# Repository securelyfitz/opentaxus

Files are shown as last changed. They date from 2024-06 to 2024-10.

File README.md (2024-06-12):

# OpenTaxus 

| [Readme](README.md) | [Using the Badge](docs/BADGE.md) | [Playing the Game](docs/GAME.md) | [Software Development](docs/DEVELOP.md) | [Badge Hardware](docs/HARDWARE.md) |
| --- | --- | --- | --- | --- |

## Badge Game

The OpenTaxus Badge is designed for playing the Attribution Game.
Similar to the board game Clue or some versions of Carmen Sandiego,
you need to figure out who the threat actor, attack tool, and victim
are for each round of the game. You do this by trading cards (or
'clues') as well as your self-entered alibi name with others
at the conference.

## Attribution Game basics

In order to play in the Attribution Game, you will need to enter a name or handle when you first turn on your badge. This will stay through power cycles. It can be cleared in your settings which will force you to enter a new one.

To trade cards with someone, scroll left or right until you get to the "OpenTaxus" screen.
Once there, press the toggle up, and place your badge edge at the top of the screen against
the same badge edge of the person you are trading with. You should see once your card has
been transmitted and you have received a card from them.

You can check your collected cards by scrolling right from the "OpenTaxus" screen.

When you collect enough cards, the one remaining is the solution that completes the phrase. There are 6 games to play through - try them all!

Please see [Playing the Game](docs/GAME.md) for more details

## Repo Contents

This repository contains the hardware and software for
the badge and game. We hope it is useful for those who wish to hack
the badges and game, anyone who wants to use the badge to learn some
circuitpython, as well as others who might like to reuse some or all
of it for other projects.

The badge hardware was designed and produced by @securityfitz, with variants being used for BSidesSF 2024 and Labscon.
The badge software is a fork of the Labscon badge software, further mangled by @rlc4, @lanrat, and @securelyfitz.

## Event Badge Designer Instructions

OpenTaxus is intended to be be a drop-in electronic badge that works from the start. While you can use the badge as it's presented here if you plan to use it for an event or organization, you may want to customize the appearance of the badge, and possibly some of the text and programming. 

### Suggested customizations:
	
#### Physical Appearance:
* Add custom artwork such as your logo to the badges KiCad files (found in the [hardware](/hardware) folder). 
*  Add in the name of the artist and contributors to the silkscreen.
* Include the repo for your code or events in the silkscreen on the back of the badge.

#### Electronic text:
* There are a number of custom strings that can be adjusted within the [genfiles.py](./configs/genfiles.py) file. In particular, you may want to change line 121 to say the name of your event or organization instead of "A mysterious group".
* The same file also includes other bits of flavor text that could be customized to match your event's theme or location.
* Changing the menu text of the badge to show your event name instead of "OpenTaxus" can be done on lines 23 and 139 of [home.py](./software/home.py)
* Sponsor names can be added within [home.py](./software/home.py) around line 144.

#### Misc:
* You may also want to change the file that you're reading now ([README.md](README.md)) to welcome your attendee's, ctf players, etc.

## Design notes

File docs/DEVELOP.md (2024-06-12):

# Develop with the OpenTaxus Badge

| [Readme](../README.md) | [Using the Badge](BADGE.md) | [Playing the Game](GAME.md) | [Software Development](DEVELOP.md) | [Badge Hardware](HARDWARE.md) |
| --- | --- | --- | --- | --- |

## Developing for the badge

Version: CircuitPython 9.0.4; Seeeduino XIAO RP2040

Make sure you use version compatible libraries

### Installing CircuitPython

When the RP2040 boots, it checks for valid data in the spi flash. If it doesn't,
it boots into USB boot-loader mode and shows up as a drive labeled RPI-RP2.
[Download and copy the .UF2 file](https://circuitpython.org/board/seeeduino_xiao_rp2040/)
to the drive and it will reboot into CircuitPython.
If you need to reinstall for any reason, short the 'BOOT' test pads while resetting
the RP2040 and it will go back to the boot-loader mode.

### Installing The Attribution Game

Once CircuitPython is installed, when the badge is plugged in it will show
both a serial port and a drive labeled CIRCUITPY. Copy the entire contents
of `/software/` in this repository to that drive. the badge will reboot and run the code.

### Provisioning the game data

The `/config/` directory contains some text files with data specific to
the game. These will be copied along with the rest of the code:

- genfiles generates a pair of keys, and creates 50 variations of game*.csv files
- game*.csv has all the possible clues for each game, and is provisioned with one signed clue per game
- seed.txt needs to be filled with a seed for the random choice of solutions
- priv.json and pub.json are generated by genfiles and contain the game keys which can be used to authenticate the signed
  clues you receive. This is generated by the controller, the public key is copied to all badges

Details about the hardware can be found in [HARDWARE](docs/HARDWARE.md)

## Software

- `/software/` contains the code on the badge
- `/flash/` contains files and tools for automatically flashing badges
- `/config/` contains tools to generate all of the encrypted badge configurations

### Architecture

Most functions are wrapped inside classes with the priority to make the top level
code more clean and readable versus sticking to a clean object model.

All functions should be non-blocking and quick to make sure the UI doesn't get
frozen and button presses don't get missed. This means stuff like checking for
enough UART valid data before reading it, and scheduling timed actions based on
timestamps instead of sleep() calls

#### Dependencies

- core circuitpython libraries: time,board,busio,pulseio,digitalio,displayio,
  terminalio
- additional adafruit libraries in `/software/lib/`: debouncer,
  ticks, displayio_ssh1106, imageload, display_text

#### Support modules

-  Fake_IRDA.py wraps the UART interface, handles enabling/disabling the
   IRDA enable pin, and stuffing/unstuffing the bytes that are transmitted
   to work with the IRDA phy in the nonstandard way we use it
-  Five_Way_Dpad.py wraps the dpad with the Adafruit Debouncer including
   all setup and a few helper functions for checking all buttons at once. The
   non-blocking update() function needs to be run periodically to capture all
   button presses.
-  sh1106_ui.py/ssd1306.py wraps the I2C display interface, handles the overall display
   view, and creates a separate group for each of the navigation pages. The
   non-blocking show() function should be called periodically to make sure the
   correct view is displayed and to manage the transition animations
-  disp.py wraps the functionality of the pages. The class handles initialization,
   managing the display view, underlying data and operations. Most of this is
   handled in a non-blocking update() function that returns the next state

## Screen

* https://www.arduino.cc/reference/en/libraries/oled-ssd1306-sh1106/
* https://docs.circuitpython.org/projects/displayio_sh1106/en/latest/api.html

Driven by: https://docs.circuitpython.org/en/latest/shared-bindings/displayio/

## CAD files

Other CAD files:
flash/dock.scad

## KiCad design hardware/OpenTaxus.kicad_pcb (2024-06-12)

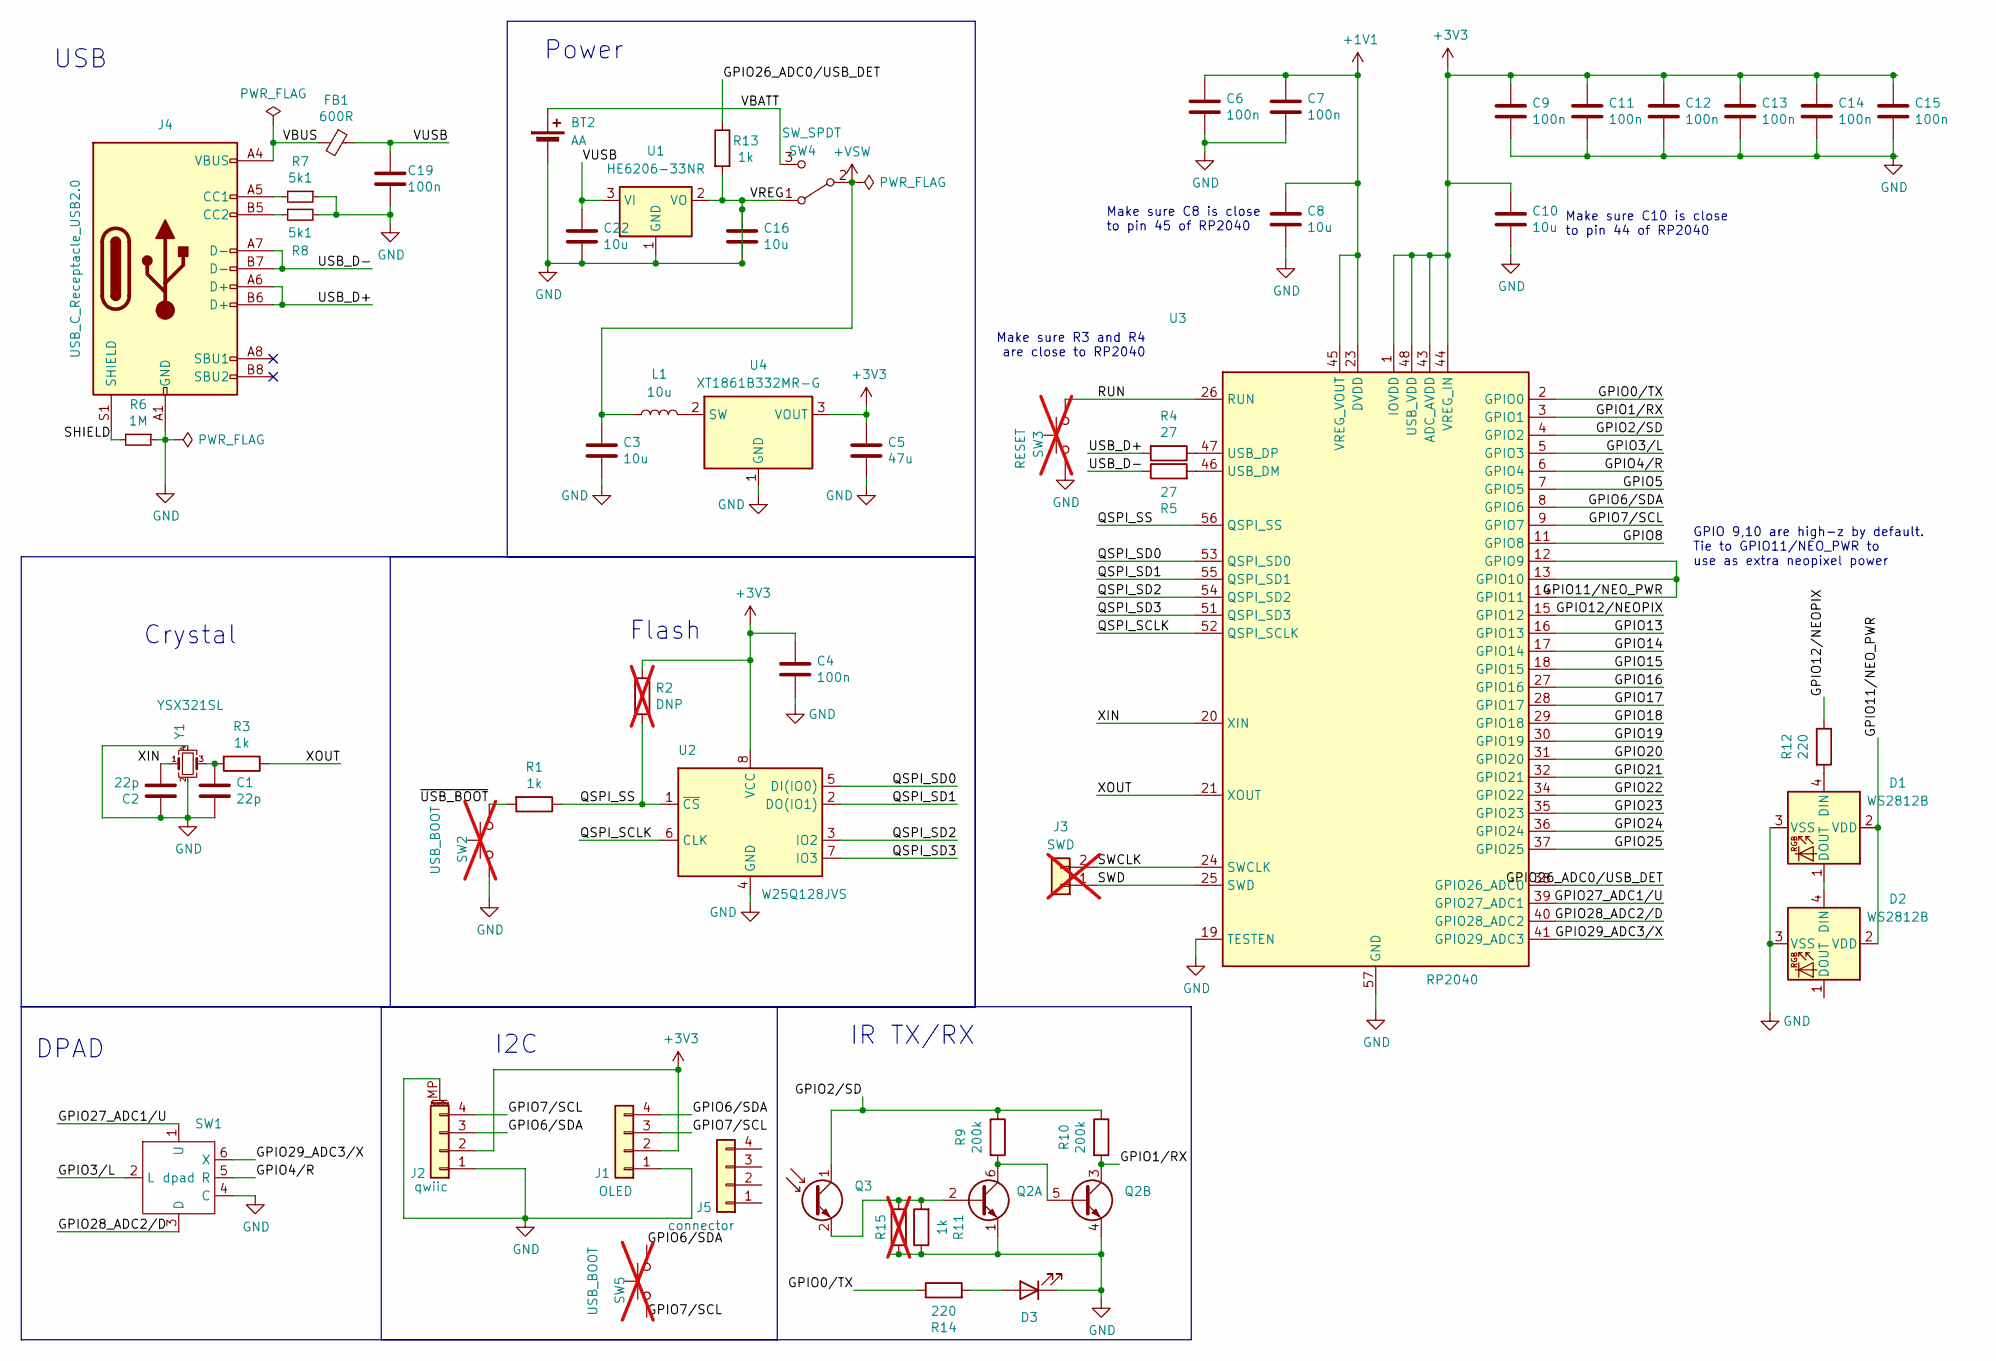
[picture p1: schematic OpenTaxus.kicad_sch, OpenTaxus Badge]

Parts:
BT2: AA; BatteryHolder_Keystone_2460_1xAA; LCSC C5290181
C1, C2: 22p; C_0402_1005Metric; LCSC C106203
C3, C8, C10, C16, C22: 10u; C_0402_1005Metric; LCSC C15525
C4, C6, C7, C9, C11, C12, C13, C14, C15, C19: 100n; C_0402_1005Metric; LCSC C100072
C5: 47u; C_0805_2012Metric; LCSC C16780
D1, D2: WS2812B; LED_WS2812B_PLCC4_1.0x1.0mm; LCSC C5349953
D3: IR12-21C/TR8; IR12-21C-TR8; LCSC C53672
FB1: 600R; L_0402_1005Metric; LCSC C76886
J1: OLED; PinHeader_1x04_P2.54mm_Vertical; LCSC C5248080
J2: qwiic; JST_SH_SM04B-SRSS-TB_1x04-1MP_P1.00mm_Horizontal; LCSC C7433425
J3: SWD; SolderJumper-2_P1.3mm_Open_RoundedPad1.0x1.5mm; LCSC DNP; not fitted
J4: USB_C_Receptacle_USB2.0; USB_C_Receptacle_HRO_TYPE-C-31-M-12; LCSC C2927038
J5: connector; PinHeader_1x04_P2.54mm_Vertical; LCSC C2902691
L1: 10u; L_1008_2520Metric; LCSC C602018
Q2: BC847BS; SOT-363_SC-70-6; LCSC C5380687
Q3: PT12-21B/TR8; PT12-21B-TR8; LCSC C264383
R1, R3, R11, R13: 1k; R_0402_1005Metric; LCSC C11702
R2, R15: DNP; R_0402_1005Metric; LCSC DNP; not fitted
R4, R5: 27; R_0402_1005Metric; LCSC C25100
R6: 1M; R_0402_1005Metric; LCSC C26083
R7, R8: 5k1; R_0402_1005Metric; LCSC C25941
R9, R10: 200k; R_0402_1005Metric; LCSC C25764
R12, R14: 220; R_0402_1005Metric; LCSC C25091
SW1: dpad; 10x10x10x9-6P-WX; LCSC C2858290
SW2, SW5: USB_BOOT; SolderJumper-2_P1.3mm_Open_RoundedPad1.0x1.5mm; LCSC DNP; not fitted
SW3: RESET; SolderJumper-2_P1.3mm_Open_RoundedPad1.0x1.5mm; LCSC DNP; not fitted
SW4: SW_SPDT; SW_SPDT_PCM12; LCSC C319020
U1: HE6206-33NR; SOT-23-3; LCSC C5199441
U2: W25Q128JVS; SOIC-8_5.23x5.23mm_P1.27mm; LCSC C97521
U3: RP2040; QFN-56-1EP_7x7mm_P0.4mm_EP3.2x3.2mm; LCSC C2040
U4: XT1861B332MR-G; SOT-23; LCSC C236396
Y1: YSX321SL; Crystal_SMD_3225-4Pin_3.2x2.5mm; LCSC C9002

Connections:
+1V1: C6.1, C7.1, C8.1, U3.23 (DVDD), U3.45 (VREG_VOUT), U3.50 (DVDD)
+3V3: C4.1, C5.1, C9.1, C10.1, C11.1, C12.1, C13.1, C14.1, C15.1, J1.2, J2.2, R2.1, U2.8 (VCC), U3.1 (IOVDD), U3.10 (IOVDD), U3.22 (IOVDD), U3.33 (IOVDD), U3.42 (IOVDD), U3.43 (ADC_AVDD), U3.44 (VREG_IN), U3.48 (USB_VDD), U3.49 (IOVDD), U4.3 (VOUT)
+VSW: C3.1, L1.1, SW4.2 (B)
/GPIO0/TX: R14.1, U3.2 (GPIO0)
/GPIO1/RX: Q2.3 (C2), R10.2, U3.3 (GPIO1)
/GPIO2/SD: Q3.1 (C), R9.1, R10.1, U3.4 (GPIO2)
/GPIO3/L: SW1.2 (L), U3.5 (GPIO3)
/GPIO4/R: SW1.5 (R), U3.6 (GPIO4)
/GPIO5: U3.7 (GPIO5)
/GPIO6/SDA: J1.4, J2.3, SW5.1, U3.8 (GPIO6)
/GPIO7/SCL: J1.3, J2.4, SW5.2, U3.9 (GPIO7)
/GPIO8: U3.11 (GPIO8)
/GPIO11/NEO_PWR: D1.2 (VDD), D2.2 (VDD), U3.12 (GPIO9), U3.13 (GPIO10), U3.14 (GPIO11)
/GPIO12/NEOPIX: R12.1, U3.15 (GPIO12)
/GPIO13: U3.16 (GPIO13)
/GPIO14: U3.17 (GPIO14)
/GPIO15: U3.18 (GPIO15)
/GPIO16: U3.27 (GPIO16)
/GPIO17: U3.28 (GPIO17)
/GPIO18: U3.29 (GPIO18)
/GPIO19: U3.30 (GPIO19)
/GPIO20: U3.31 (GPIO20)
/GPIO21: U3.32 (GPIO21)
/GPIO22: U3.34 (GPIO22)
/GPIO23: U3.35 (GPIO23)
/GPIO24: U3.36 (GPIO24)
/GPIO25: U3.37 (GPIO25)
/GPIO26_ADC0/USB_DET: R13.1, U3.38 (GPIO26_ADC0)
/GPIO27_ADC1/U: SW1.1 (U), U3.39 (GPIO27_ADC1)
/GPIO28_ADC2/D: SW1.3 (D), U3.40 (GPIO28_ADC2)
/GPIO29_ADC3/X: SW1.6 (X), U3.41 (GPIO29_ADC3)
/QSPI_SCLK: U2.6 (CLK), U3.52 (QSPI_SCLK)
/QSPI_SD0: U2.5 (DI(IO0)), U3.53 (QSPI_SD0)
/QSPI_SD1: U2.2 (DO(IO1)), U3.55 (QSPI_SD1)
/QSPI_SD2: U2.3 (IO2), U3.54 (QSPI_SD2)
/QSPI_SD3: U2.7 (IO3), U3.51 (QSPI_SD3)
/QSPI_SS: R1.1, R2.2, U2.1 (~CS), U3.56 (QSPI_SS)
/RUN: SW3.1, U3.26 (RUN)
/SHIELD: J4.S1 (SHIELD), R6.2
/SWCLK: J3.2, U3.24 (SWCLK)
/SWD: J3.1, U3.25 (SWD)
/USB_D+: J4.A6 (D+), J4.B6 (D+), R4.2
/USB_D-: J4.A7 (D-), J4.B7 (D-), R5.1
/VBATT: BT2.1 (+), SW4.3 (C)
/VBUS: FB1.2, J4.A4 (VBUS), J4.A9 (VBUS), J4.B4 (VBUS), J4.B9 (VBUS)
/VREG: C16.1, R13.2, SW4.1 (A), U1.2 (VO)
/VUSB: C19.1, C22.1, FB1.1, U1.3 (VI)
/XIN: C2.2, U3.20 (XIN), Y1.1
/XOUT: R3.1, U3.21 (XOUT)
/~USB_BOOT: R1.2, SW2.1
GND: BT2.2 (-), C1.2, C2.1, C3.2, C4.2, C5.2, C6.2, C7.2, C8.2, C9.2, C10.2, C11.2, C12.2, C13.2, C14.2, C15.2, C16.2, C19.2, C22.2, D1.3 (VSS), D2.3 (VSS), D3.2 (K), J1.1, J2.1, J2.MP (MountPin), J4.A1 (GND), J4.A12 (GND), J4.B1 (GND), J4.B12 (GND), Q2.1 (E1), Q2.4 (E2), R6.1, R7.1, R8.2, R11.1, R15.1, SW1.4 (C), SW2.2, SW3.2, U1.1 (GND), U2.4 (GND), U3.19 (TESTEN), U3.57 (GND), U4.1 (GND), Y1.2, Y1.4
unnamed: C1.1, R3.2, Y1.3
unnamed: D1.4 (DIN), R12.2
unnamed: D1.1 (DOUT), D2.4 (DIN)
unnamed: D3.1 (A), R14.2
unnamed: J4.A5 (CC1), R7.2
unnamed: J4.B5 (CC2), R8.1
unnamed: Q2.2 (B1), Q3.2 (E), R11.2, R15.2
unnamed: Q2.5 (B2), Q2.6 (C1), R9.2
unnamed: R5.2, U3.46 (USB_DM)
unnamed: R4.1, U3.47 (USB_DP)
unnamed: L1.2, U4.2 (SW)

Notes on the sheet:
DPAD
Make sure C10 is close to pin 44 of RP2040
Make sure C8 is close to pin 45 of RP2040
IR TX/RX
USB
I2C
Make sure R3 and R4 are close to RP2040
Flash
Crystal
Power
GPIO 9,10 are high-z by default. Tie to GPIO11/NEO_PWR to use as extra neopixel power

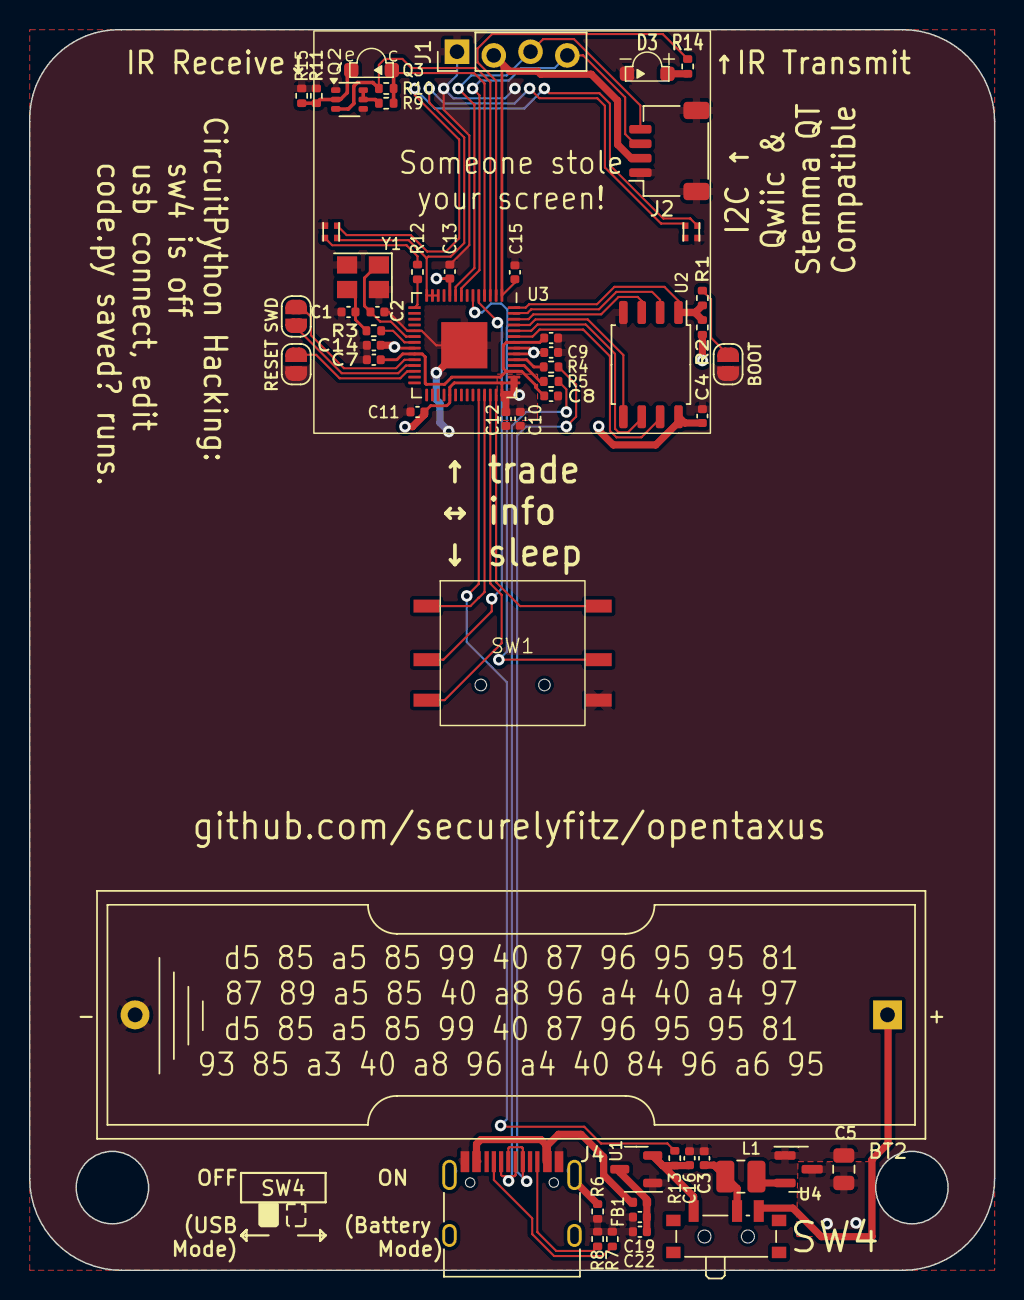
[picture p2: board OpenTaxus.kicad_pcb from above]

Board: 2 copper layers, 66.7 x 85.7 mm, 54 parts (0 on the bottom side), 47 nets.

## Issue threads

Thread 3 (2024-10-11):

fix flash.py to be cross-platform

securelyfitz, 2024-10-11:
right now linux-specific.
should be able to contain the changes to mountnode,umounpoint, and copytodevice()

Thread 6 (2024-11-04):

New Directory Layout

rlc4, 2024-11-04:
The repo in general needs a better layout, and with that in mind there was a discussion about what would likely work best.
Especially as we want to have a way for people to submit their own badges back to the repo.

With that in mind, the planned layout is as follows:

* hardware
  * OpenTaxus - The original badge
    * pcb - All design files for the PCB design (prefer Kicad or other OSS format)
    * images - Pictures of the badge, including pre-production 3d renderings
    * fabrication - Files to be sent to a fabricator: Gerbers, BOM, CPL, etc.
  * BSidesPDX
    * pcb
    * images
    * fabrication
  * Support - Supporting hardware, such as flashing rigs, dpad extensions, etc
    * FlashRig - Files needed to 3d print flashing rig holding 10 badges at a time

* software
  * scripts - all scripts for flashing or making a distribution of the badge software, including OS specific
  * src - all source for the badge EXCEPT GAME CODE
  * lib - library files
    * Readme.md - documentation on where all of the library files were source from, along with version information
    * *.mpy - downloaded libraries
    * *.py - locally developed libraries (ex: disp.py)
  * games -
    * attribution - the original game, also used for BsidesSF 2024
      * game.py - entry point for the specific game
    * trick-or-treat - BSidesPDX 2024 game
      * game.py - entry point for the specific game

i'm sure that I've forgotten some of the layout that will support the current future growth, so please make additions and changes to this and update comments for more clarity.

securelyfitz, 2025-05-19:
Thoughts, that don't need to change anything and i may have already written somewhere else:
- images and fabrication files are like 'compiled outputs' and i feel like they are better placed in releases than in repo
- I think only the base opentaxus should be in the repo  - variants could be in branches of the repo, but keeping them in the main repo is going to get big quick. Links to them or a list of them in docs would be good though
- not sure what would go in src vs lib
- i broke down software into controller (scripts) and badge (everything else). Splitting that into controller, badge, and game seems like a logical breakdown to me
- there is still the issue of game-specific controller stuff. So perhaps each game should have a controller and badge subdir?

securelyfitz, 2025-05-20:
Applied in e7f9212
only change from our last discussion - i removed the 'games' subdir, so that games live in /software next to /software/base which made the hierarchy a little smoother, i'm ok with this changing though.

Closed 2025-05-20.

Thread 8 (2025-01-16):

Ground pins not connected?

a3l6, 2025-01-16:
Hi, I'm fairly new to PCB design, but when I load up the file in KiCad, all the ground pins are not connected together. Is this something that is supposed to happen, or is it just a bug?

a3l6, 2025-01-16:
@securelyfitz @rlc4 @SynapticRewrite Is there a different version of the PCB that was not uploaded?

securelyfitz, 2025-01-16:
The grounds are mostly connected by a ground plane/pour, which is an area defined to be ground unless there's something else there.
You need to tell kicad to calculate those anytime there's a change to the other traces on the board - press 'b' to do that.

The latest version of the board was the fork for BsidesPDX. The biggest changes were resistor values to better tune the IR transmission - the rest were cosmetic. I think i still need to backport the resistor changes, will check on that later today.

https://github.com/pdxbadgers/badge-2024

securelyfitz, 2025-05-20:
closing, current head has resistor values fixed and ground pour generated

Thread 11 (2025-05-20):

define game/badge interface

securelyfitz, 2025-05-20:
Currently, games are monolithic.
In the near future, common libraries will be broken out separately so they don't have to be duplicated per-game.
In the long run, we'd like the game mechanics to all 'live' in a single screen inside the main firmware, which could handle file access, settings, flashy lights, and more.

Future games will implement a standard interface to the main firmware:
- init(framebuffer), called once, where the main firmware gives the game a pointer to a framebuffer
- update(buttons), nonblocking and called periodically, is the game's asynchronous update loop. The game must accept that this probably won't be periodic or regular. Optionally, any inputs that are pressed are passed through here
- sleep(), which is called before the main firmware expects to be handling other tasks for a period of time, or the badge is going to sleep. The game should flush any important info to files and be prepared to get terminated - but should stay ready to handle another update() as soon as the main firmware is done with it's tasks.

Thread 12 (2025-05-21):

prototype 'build' script

securelyfitz, 2025-05-21:
In the top level directory, there should be an interactive 'build' script. this script will:
- ask the user the name of the badge and create this top level directory
- copy the /hardware/ files to the new badge directory
- run the hardware customizer script (if it exists)
- copy the /software/base files to the new badge directory
- prompt the user to choose a game from the options in /software/
- copy those game files over to the new badge directory on top of the base files
- run the new badge customizer script (if it exists)
- start flashing badges

All prompts should be saved in a .cfg file that is checked first. reruning the build script with the cfg file present should get the identical results.

The hardware customizer script will at some point include some automated customization of the hardware like changing strings, adding artwork, and changing the cutout size.

The game customizer script has the job of initializing the game structure/data and generating all the per-badge details. For example, generating the keys and randomizing the results for the attribution game would happen here.

Once complete, the badge directory should have new files that look something like:

- mynewbadgename.cfg
- mynewbadgename
  - hardware
    - pcb
    - dock
  - admin (this has the generator and the flasher)
  - firmware (this is copied to every badge)
  - data (this has per-badge varying stuff)

There are definitely some wheels being reinvented here - would be glad to swap those out for my sketchy solutions....

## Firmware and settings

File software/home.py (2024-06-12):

# from disp import disp
# import terminalio
# import displayio
# import random
# from ssd1306_ui import box
# from adafruit_display_text.label import Label
import time

# BLACK=0x000000
# WHITE=0xFFFFFF

# this class manages the home display and navigation
# it also presents the new user process when no name is defined
class home:

    def __init__(self, l_disp, dpad):
        # self.group=group
        self.dpad=dpad
        self.game=None
        self.thanks = False # we have 2 main displays, directions and thanks
        self.disp = l_disp

        self.disp.setHeader("OpenTaxus")

        # ToDo: breakout badge setup into it's own thing, should be checked in code.py
        # get the username from file. This duplicates the work done by game.read_name()
        # but i'd rather add file i/o here than add display management there
        try:
            with open("data/myname.txt",'r') as file:
                name=file.readline().rstrip()
        except OSError as e:
            print(e)
            name=""

        #if there's no file or it's blank, give some instructions and ask for a name
        # ToDo: Move to config?
        # ToDo: Break out the instructions message into a config item
        if name=="":
            while True:
                self.dpad.update()
                if self.dpad.x.fell:
                    break
                self.disp.setText([ "The", "Attribution", "Game!"], align="c")
                time.sleep(.01)

            while True:
                self.dpad.update()
                if self.dpad.x.fell:
                    break
                self.disp.setText([
                    "Meet people & trade",
                    "clues to attribute",
                    "the attack",
                    "You don't have",
                    "a handle yet!",
                    "Your handle will",
                    "be shared when you",
                    "trade in the game."
                ])
                time.sleep(.01)

            # nameEntry blocks, not fixing
            name=self.nameEntry()

            while True:
                self.dpad.update()
                if self.dpad.x.fell:
                    break
                self.disp.setText([
                    "Welcome to the game",
                    name,
                    "press '^' & point @",
                    "another to trade",
                    "contact & clues!",
                    "press '<' to get to",
                    "settings and a list",
                    "of alibis",
                    "press '>' to get to",
                    "your clue collection",
                    ""
                    "Collect enough",
                    "clues to figure",
                    "out what happened",
                    "Have fun!"
                ])
                time.sleep(.01)

    # show a string and handle text input
    def nameEntry(self):
        instructions=["Enter your handle","Press to save"]
        player_name = [" "] * 20  # max name length
        chars = "abcdefghijklmnopqrstuvwxyz0123456789!@#$%^&*()'<>.?/|\\{}[] "
        cindex = 0
        nindex = 0
        player_name[nindex] = chars[cindex]
        self.disp.setTextCursor( instructions + ["".join(player_name)], (nindex,2) )

        while True:
            self.dpad.update()
            if self.dpad.u.fell:
                # u increments through the character set for names
                cindex = (cindex + 1) % len(chars)
                player_name[nindex] = chars[cindex]
                self.disp.setTextCursor( instructions + ["".join(player_name)], (nindex,2) )
            elif self.dpad.d.fell:
                # d decrements through the character set for names
                cindex = (cindex - 1) % len(chars)
                player_name[nindex] = chars[cindex]
                self.disp.setTextCursor( instructions + ["".join(player_name)], (nindex,2) )
            elif self.dpad.l.fell:
                # l moves to the previous char
                nindex = nindex - 1 if nindex > 0 else 0
                cindex = chars.find(player_name[nindex])
                self.disp.setTextCursor( instructions + ["".join(player_name)], (nindex,2) )
            elif self.dpad.r.fell:
                # r moves to the next char
                nindex = nindex + 1 if nindex < len(player_name)-1 else len(player_name) - 1
                # move cindex to existing character at slot
                cindex = chars.find(player_name[nindex])
                self.disp.setTextCursor( instructions + ["".join(player_name)], (nindex,2) )
            elif self.dpad.x.fell:
                # x means we're done. Verify and resume.
                self.disp.setText(["Saving your handle:", str.rstrip("".join(player_name))])
                self.disp.setText("Saving handle")
                try:
                    with open("data/myname.txt",'w') as file:
                        file.write("".join(player_name))
                except OSError as e:
                    print(e)
                print("player_name: {}".format("".join(player_name)))
                return str.rstrip("".join(player_name))
            time.sleep(.01)



    def update(self):
        # show contents, process keypresses
        # self.disp.hidden=False
        self.disp.setHeader("OpenTaxus")

        if self.thanks:
            self.disp.setHeader("Sponsors")
            if self.disp.setText([
                "Thank you to our",
                "Sponsors!",
            ]): 
                if self.dpad.u.fell:
                    return "trade"
                elif self.dpad.d.fell:
                    return "sleep"
            if self.dpad.x.fell: self.thanks = not self.thanks
            elif self.dpad.l.fell: 
                return "alibis"
            elif self.dpad.r.fell:
                return "clues"
        else:
            #this is causing oom!
            if self.disp.setText(self.game.solution_string):
                if self.dpad.u.fell:
                    return "trade"
                elif self.dpad.d.fell:
                    return "sleep"
            if self.dpad.l.fell:
                return "alibis"
            elif self.dpad.r.fell:
                return "clues"
            elif self.dpad.x.fell: self.thanks = not self.thanks
        return "home"

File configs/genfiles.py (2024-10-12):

#!/usr/bin/python3
import random
import os
import sys
import binascii
import adafruit_rsa
import json

# number of variants to generate
num_variants = 50
working_dir = os.path.dirname(os.path.realpath(__file__))
(public_key, private_key) = adafruit_rsa.newkeys(512)
hash_method="SHA-256"

#todo: clean this up, put pub.json into ../software
public_obj = {"public_key_arguments": [public_key.n, public_key.e]}

f=open("pub.json", "w")
f.write(json.dumps(public_obj))
f.close()

f=open("../software/pub.json", "w")
f.write(json.dumps(public_obj))
f.close()

f=open("priv.json", "w")
private_obj = {
    "private_key_arguments": [
        private_key.n,
        private_key.e,
        private_key.d,
        private_key.p,
        private_key.q,
    ]
}
f.write(json.dumps(private_obj))
f.close()

# set the random seed so that game files are deterministic
try:
    with open(os.path.join(working_dir, "seed.txt"), 'r') as file:
        file_content = file.read()
        if len(file_content) < 10:
            print("WARNING: seed.txt short")
        random.seed(file_content)
except Exception as e:
    print("Unable to open seed.txt: ", e)
    sys.exit(5)


#build $file_count unique files for separate badges.
#each file will be a CSV of all the T,A, and V for that game
#each file will also have a unique * line with one clue 
def gen_game_files(game_num,clues,solution_string,file_count=None):
    #we'll re-write this for each file, so build a string
    #one line per clue, coded with the clue type
    clue_csv="#,"+solution_string+"\n"
    for typename, cluetype in clues.items():
        for clue in cluetype:
            print(clue)
            clue_csv+=typename+","+clue+",0,,\n"

    #select the winning combo - randomly choose a threat, attack, and victim
    for typename, cluetype in clues.items():
        index=random.randrange(len(cluetype))
        print("index=",index)
        print("removing ",cluetype[index])
        print(cluetype)
        cluetype.remove(cluetype[index])
        print(cluetype)

    #combine what's left so we can give one each
    all_clues=[]
    for typename, cluetype in clues.items():
        all_clues+=cluetype
        print(all_clues)
    
    #if we don't specify how many files, do one of each.
    if file_count is None: file_count=len(all_clues)

    for i in range(file_count):
        #make the dir if not already there
        #create the game file
        filename=os.path.join(working_dir, "data/", str(i), "game"+str(game_num)+".csv")
        print("creating: "+filename)
        os.makedirs(os.path.join(working_dir, "data/",str(i)),exist_ok=True)
        f=open(filename, "w")
        #write the generated CSV, followed by one line with a * containing a single clue
        my_clue=all_clues[i%len(all_clues)]
        my_sig=adafruit_rsa.sign(my_clue.encode(), private_key, hash_method)
        f.write(clue_csv+"*,"+my_clue+","+str(binascii.b2a_base64(my_sig))+"\n")
        f.close()

gen_game_files(0,
        {
            "AI":["Lore","WOPR","Skynet"],
            "tool":["Borg","NORAD","t1000"],
            "fix":["Data","Tic-Tac-Toe","t800"],
            },
        "[AI] tried to take over using [tool] but was thwarted by [fix]",
    num_variants)


gen_game_files(1,
    {
            "year":["2019","1984","1997","2015"],
            "ai":["Pris","WOPR","Skynet","Ultron"],
            "what":["Sebastia","NORAD","everything","Sokivia"],
            },
        "In [year] [ai] conquered [what].",
    num_variants)


gen_game_files(2,
        {
            "Company":["Terrell Corporation","Yoyodyne Propulsion","Weyland-Yutani","PlayTronics","Ellingson Mineral Company",],
            "startup":["Algofy","EyeTech","AiCept","InvoQTy","Uzzy","EgoBots",],
            "tool":["SOAR","DFIR","IR Management","GRC","Supply Chain Security","Cloud IAM",],
            },
"[Company] has just ann`ounced intent to acquire [startup] to build the industry's most advanced AI-powered [tool].",
    num_variants)


gen_game_files(3,
        {
            "organization":["A mysterious group"],
            "event":["disco rave","glamping trip","scuba live-aboard","picnic","festival",],
            "topic":["OWASP Top 10","CISSP domains","NIST CSF Functions","ISO 27035 - Incident Management",],
            "location":["Oakland","San Jose","Farralons","Alameda","Napa",],
            },
        "[organization] is starting a spinoff [event] focused on [topic] that will be based out of [location].",
    num_variants)


gen_game_files(4,
        {
            "swag":["card","frisbee","lightsaber","lipbalm,sticker"],
            "location":["San Francisco","Oakland","Marin","San Mateo","Alameda","Contra Costa"],
            "activity":["swim","drive","ski","snorkel",],
            },
        "Symmetrical [swag] stacking. Just like the [location] mass [activity] of 2020.",
    num_variants)



gen_game_files(5,
        {
            "murderer":["Col. Mustard", "Dr. Scarlett", "Mr. Green", "Ms. White", "Mx. Peacock", "Prof. Plum"],
            "weapon":["Dagger", "Lead Pipe", "Revolver", "Rope", "Wrench"],
            "location":["Ballroom", "Billiard Room", "Conservatory", "Dining Room", "Hall", "Kitchen", "Lounge", "Study"],
            },
        "It was [murderer] with the [weapon] in the [location]",
    num_variants)

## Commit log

2024-06-12 Initial commit. Much work still to be done.
    [bsidessf-24.kicad_pcb, bsidessf-24.kicad_sch, dock.scad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]
2024-06-12 De-branded the kicad files
    [OpenTaxus.kicad_pcb, OpenTaxus.kicad_sch, bsidessf-24.kicad_pcb]
2024-06-12 More debranding
    [OpenTaxus.kicad_pcb, OpenTaxus.kicad_sch]
2024-06-12 Removed OH logo for licensing clarity
    [OpenTaxus.kicad_pcb]
2024-08-30 Fine tuning R11 and R14 so badges can communicate up to 1 inch apart.
    [OpenTaxus.kicad_sch]
2024-10-11 fix flash.py data dir path
    mountpoint didn't have a trailing / so it was copying to mountpointdata instead of mountpoint/data
2024-10-11 fixing sample game files
    some categories didn't fit the [category] substrings, so the solution string would never show.
    [genfiles.py]
2024-10-12 fix #5 by writing out /software/pub.json too
    [genfiles.py]
